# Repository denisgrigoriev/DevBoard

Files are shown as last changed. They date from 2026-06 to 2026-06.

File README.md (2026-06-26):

# Devboard project

in this project i would be using kicad to create the schematics and pcb layout
and JLCPCB to manufacture the actual pcb.





Parts used:

### Bill of Materials (BOM)

| Part Number | Type | LCSC Part # | Qty | Source | Ext. Price |
| :--- | :---: | :---: | :---: | :---: | :---: |
| **CL05A105KA5NQNC** | Basic | C52923 | 4 | JLCPCB | $0.0612 |
| **MCP1700T-3302E/TT** | Extended | C39051 | 5 | JLCPCB | $2.1540 |
| **0402CG330J500NT** | Basic | C1562 | 4 | JLCPCB | $0.0232 |
| **0402WGF1001TCE** | Basic | C11702 | 4 | JLCPCB | $0.0164 |
| **0402WGF5101TCE** | Basic | C25905 | 4 | JLCPCB | $0.0048 |
| **X322512MSB4SI** | Basic | C9002 | 2 | JLCPCB | $0.1988 |
| **CL10A106KP8NNNC** | Basic | C19702 | 4 | JLCPCB | $0.2208 |
| **0402WGJ0270TCE** | Extended | C25156 | 20 | JLCPCB | $0.0160 |
| **RP2040** | Extended | C2040 | 2 | JLCPCB | $1.9584 |
| **CL05B104KO5NNNC** | Basic | C1525 | 22 | JLCPCB | $0.1364 |
| **W25Q16JVUXIQ** | Extended | C2843335 | 2 | JLCPCB | $3.1444 |
| **0402WGF1002TCE** | Basic | C25744 | 2 | JLCPCB | $0.0070 |
| **TYPE-C-31-M-12** | Extended | C165948 | 2 | JLCPCB | $0.3662 |
| **TS-1088-AR02016** | Basic | C72047 | 2 | JLCPCB | $0.1098 |

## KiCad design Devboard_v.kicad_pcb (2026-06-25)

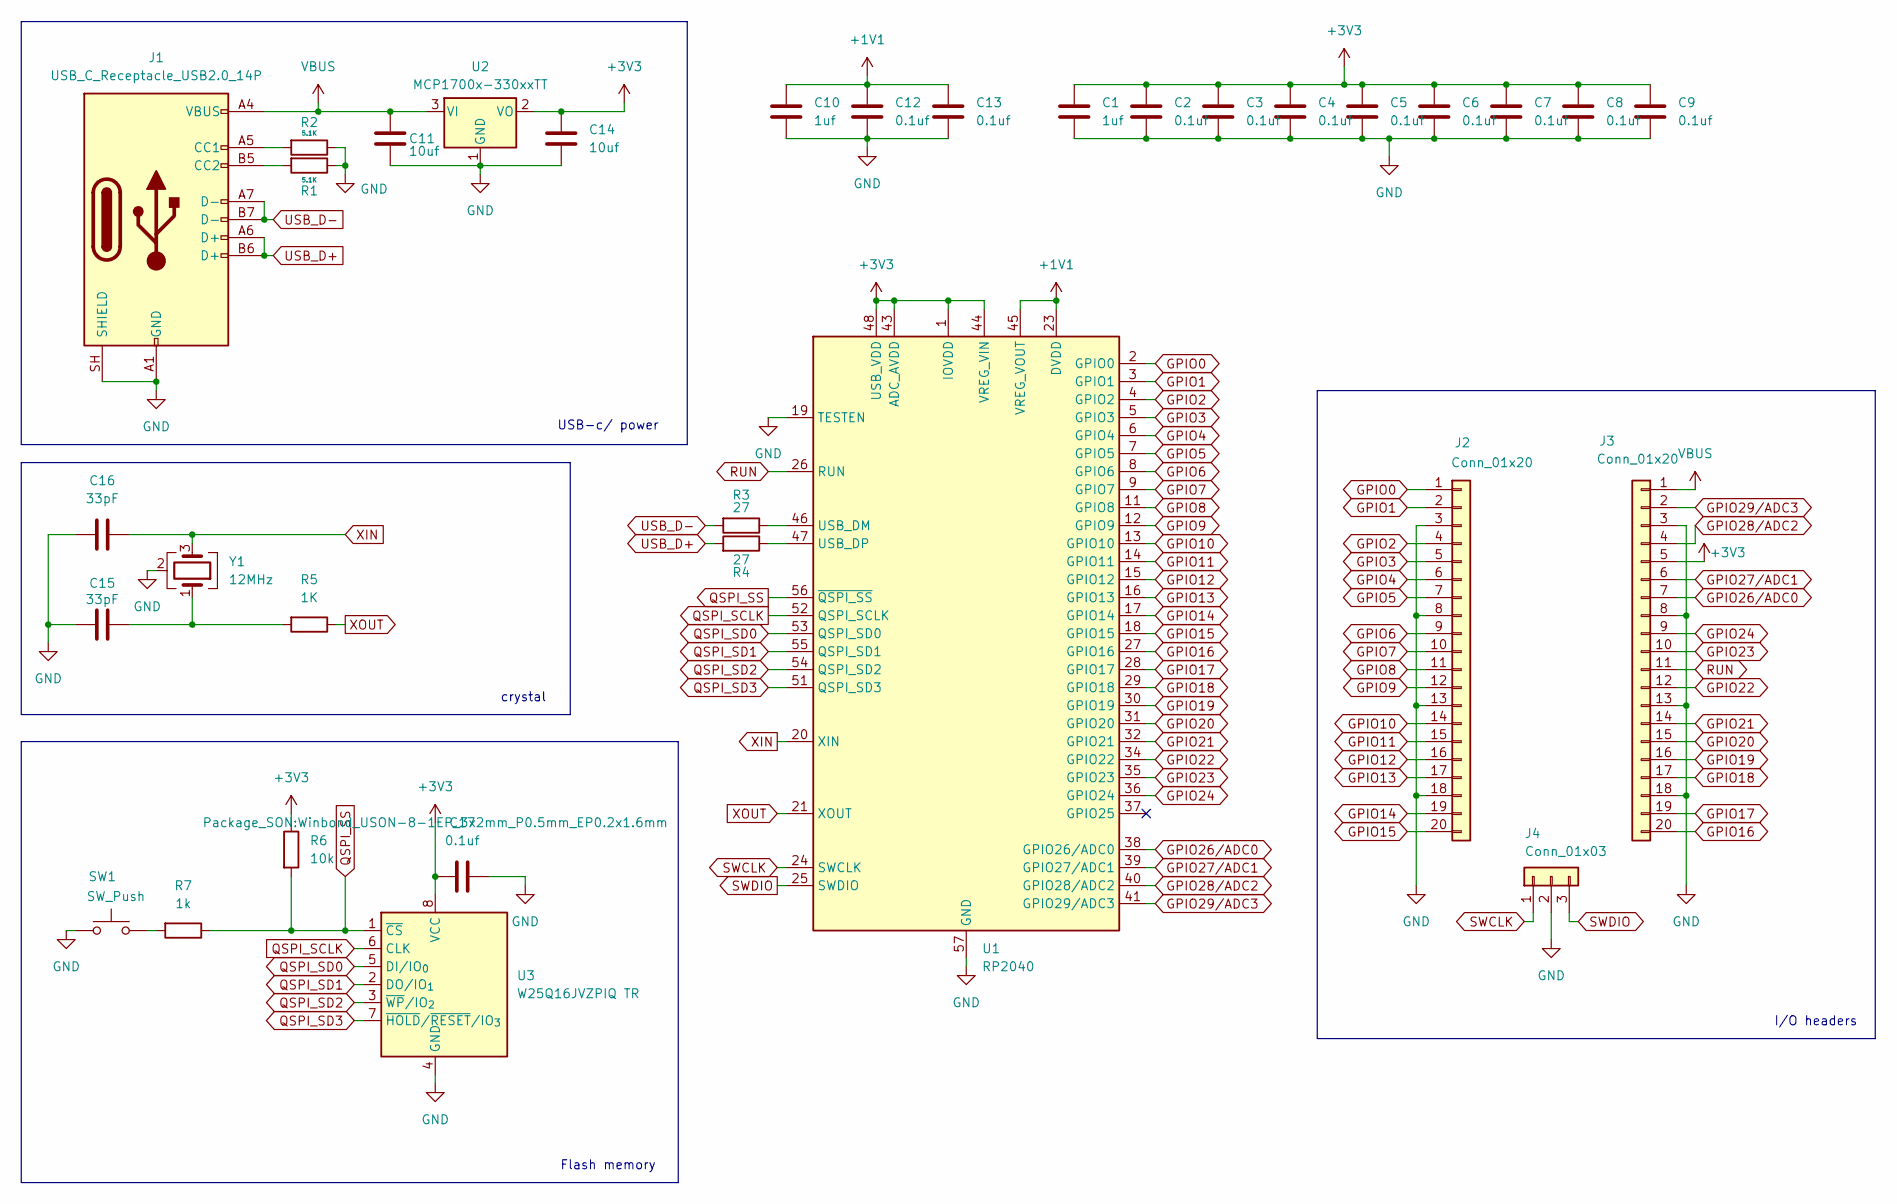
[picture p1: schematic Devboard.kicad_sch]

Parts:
C1, C10: 1uf; C_0402_1005Metric
C2, C3, C4, C5, C6, C7, C8, C9, C12, C13, C17: 0.1uf; C_0402_1005Metric
C11, C14: 10uf; C_0603_1608Metric
C15, C16: 33pF; C_0402_1005Metric
J1: USB_C_Receptacle_USB2.0_14P; USB_C_Receptacle_HRO_TYPE-C-31-M-12
J2, J3: Conn_01x20; PinHeader_1x20_P2.54mm_Vertical
J4: Conn_01x03; PinHeader_1x03_P2.54mm_Vertical
R1, R2: 5.1K; R_0402_1005Metric
R3, R4: 27; R_0402_1005Metric
R5: 1K; R_0402_1005Metric
R6: 10k; R_0402_1005Metric
R7: 1k; R_0402_1005Metric
SW1: SW_Push; SW_Push_SPST_NO_Alps_SKRK
U1: RP2040; QFN-56-1EP_7x7mm_P0.4mm_EP3.2x3.2mm
U2: MCP1700x-330xxTT; SOT-23
U3: W25Q16JVZPIQ TR; Winbond_USON-8-1EP_3x2mm_P0.5mm_EP0.2x1.6mm
Y1: 12MHz; Crystal_SMD_3225-4Pin_3.2x2.5mm

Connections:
+1V1: C10.1, C12.1, C13.1, U1.23 (DVDD), U1.45 (VREG_VOUT), U1.50 (DVDD)
+3V3: C1.1, C2.1, C3.1, C4.1, C5.1, C6.1, C7.1, C8.1, C9.1, C14.1, C17.2, J3.5, R6.1, U1.1 (IOVDD), U1.10 (IOVDD), U1.22 (IOVDD), U1.33 (IOVDD), U1.42 (IOVDD), U1.43 (ADC_AVDD), U1.44 (VREG_VIN), U1.48 (USB_VDD), U1.49 (IOVDD), U2.2 (VO), U3.8 (VCC)
GND: C1.2, C2.2, C3.2, C4.2, C5.2, C6.2, C7.2, C8.2, C9.2, C10.2, C11.2, C12.2, C13.2, C14.2, C15.2, C16.2, C17.1, J1.A1 (GND), J1.A12 (GND), J1.B1 (GND), J1.B12 (GND), J1.SH (SHIELD), J2.3, J2.8, J2.13, J2.18, J3.3, J3.8, J3.13, J3.18, J4.2, R1.1, R2.1, SW1.1, U1.19 (TESTEN), U1.57 (GND), U2.1 (GND), U3.4 (GND), Y1.2 (G), Y1.4 (G)
GPIO0: J2.1, U1.2 (GPIO0)
GPIO1: J2.2, U1.3 (GPIO1)
GPIO2: J2.4, U1.4 (GPIO2)
GPIO3: J2.5, U1.5 (GPIO3)
GPIO4: J2.6, U1.6 (GPIO4)
GPIO5: J2.7, U1.7 (GPIO5)
GPIO6: J2.9, U1.8 (GPIO6)
GPIO7: J2.10, U1.9 (GPIO7)
GPIO8: J2.11, U1.11 (GPIO8)
GPIO9: J2.12, U1.12 (GPIO9)
GPIO10: J2.14, U1.13 (GPIO10)
GPIO11: J2.15, U1.14 (GPIO11)
GPIO12: J2.16, U1.15 (GPIO12)
GPIO13: J2.17, U1.16 (GPIO13)
GPIO14: J2.19, U1.17 (GPIO14)
GPIO15: J2.20, U1.18 (GPIO15)
GPIO16: J3.20, U1.27 (GPIO16)
GPIO17: J3.19, U1.28 (GPIO17)
GPIO18: J3.17, U1.29 (GPIO18)
GPIO19: J3.16, U1.30 (GPIO19)
GPIO20: J3.15, U1.31 (GPIO20)
GPIO21: J3.14, U1.32 (GPIO21)
GPIO22: J3.12, U1.34 (GPIO22)
GPIO23: J3.10, U1.35 (GPIO23)
GPIO24: J3.9, U1.36 (GPIO24)
GPIO26/ADC0: J3.7, U1.38 (GPIO26/ADC0)
GPIO27/ADC1: J3.6, U1.39 (GPIO27/ADC1)
GPIO28/ADC2: J3.4, U1.40 (GPIO28/ADC2)
GPIO29/ADC3: J3.2, U1.41 (GPIO29/ADC3)
unnamed: C15.1, R5.2, Y1.1
unnamed: J1.A5 (CC1), R2.2
unnamed: J1.B5 (CC2), R1.2
unnamed: R7.2, SW1.2
unnamed: R3.1, U1.46 (USB_DM)
unnamed: R4.1, U1.47 (USB_DP)
QSPI_SCLK: U1.52 (QSPI_SCLK), U3.6 (CLK)
QSPI_SD0: U1.53 (QSPI_SD0), U3.5 (DI/IO_{0})
QSPI_SD1: U1.55 (QSPI_SD1), U3.2 (DO/IO_{1})
QSPI_SD2: U1.54 (QSPI_SD2), U3.3 (~WP/IO_{2})
QSPI_SD3: U1.51 (QSPI_SD3), U3.7 (~HOLD/~RESET/IO_{3})
QSPI_SS: R6.2, R7.1, U1.56 (~QSPI_SS), U3.1 (~CS)
RUN: J3.11, U1.26 (RUN)
SWCLK: J4.1, U1.24 (SWCLK)
SWDIO: J4.3, U1.25 (SWDIO)
USB_D+: J1.A6 (D+), J1.B6 (D+), R4.2
USB_D-: J1.A7 (D-), J1.B7 (D-), R3.2
VBUS: C11.1, J1.A4 (VBUS), J1.A9 (VBUS), J1.B4 (VBUS), J1.B9 (VBUS), J3.1, U2.3 (VI)
XIN: C16.1, U1.20 (XIN), Y1.3
XOUT: R5.1, U1.21 (XOUT)

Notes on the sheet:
I/O headers
Flash memory
crystal
USB-c/ power

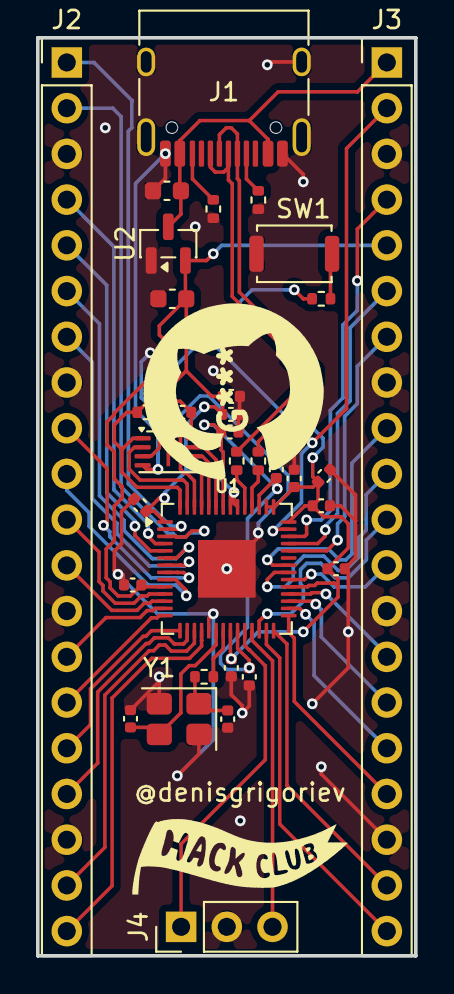
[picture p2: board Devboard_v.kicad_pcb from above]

Board: 2 copper layers, 21.0 x 51.0 mm, 33 parts (0 on the bottom side), 52 nets.

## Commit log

2026-06-25 PCB files
2026-06-25 Add README for Devboard project with BOM
    This README provides details about the Devboard project, including the tools used for PCB design and manufacturing, along with a Bill of Materials (BOM) listing the parts used.
2026-06-26 .sch file
    [Devboard.kicad_sch]
